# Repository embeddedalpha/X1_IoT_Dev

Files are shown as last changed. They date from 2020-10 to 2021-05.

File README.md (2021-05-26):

# Wi-Fi & LoRA enabled Security Node  

### Check out GrabCAD for STEP Model: https://grabcad.com/library/home-surveillance-node-v1-1
### With generous help from JLCPCB. Check them out on jlcpcb.com

1b83d655-3295-41b9-9d5b-cecb78344af5

Render_1

IOTv1

IOTv1_iso

IOTv1_iso_back

IOTv1_Front

IOTv1_Back

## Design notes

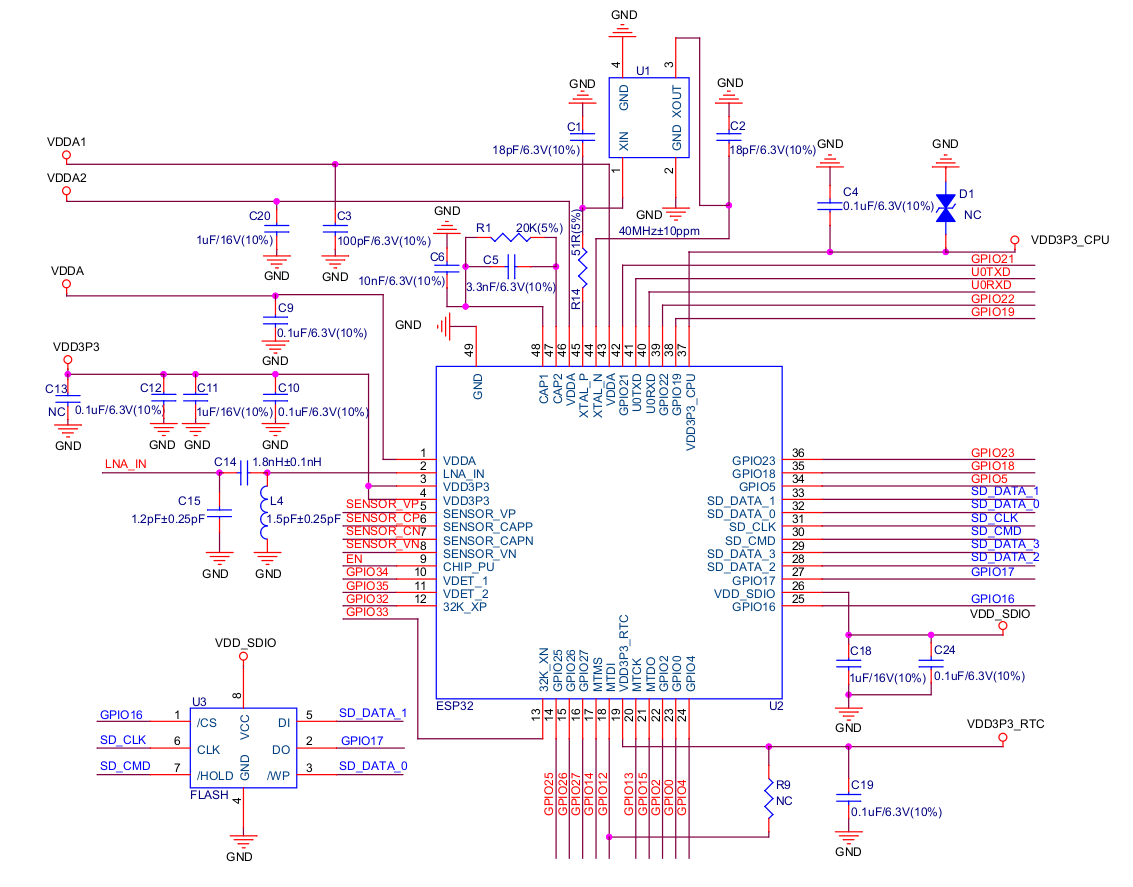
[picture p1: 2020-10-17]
Documents/ESP32-PICO-D4.png

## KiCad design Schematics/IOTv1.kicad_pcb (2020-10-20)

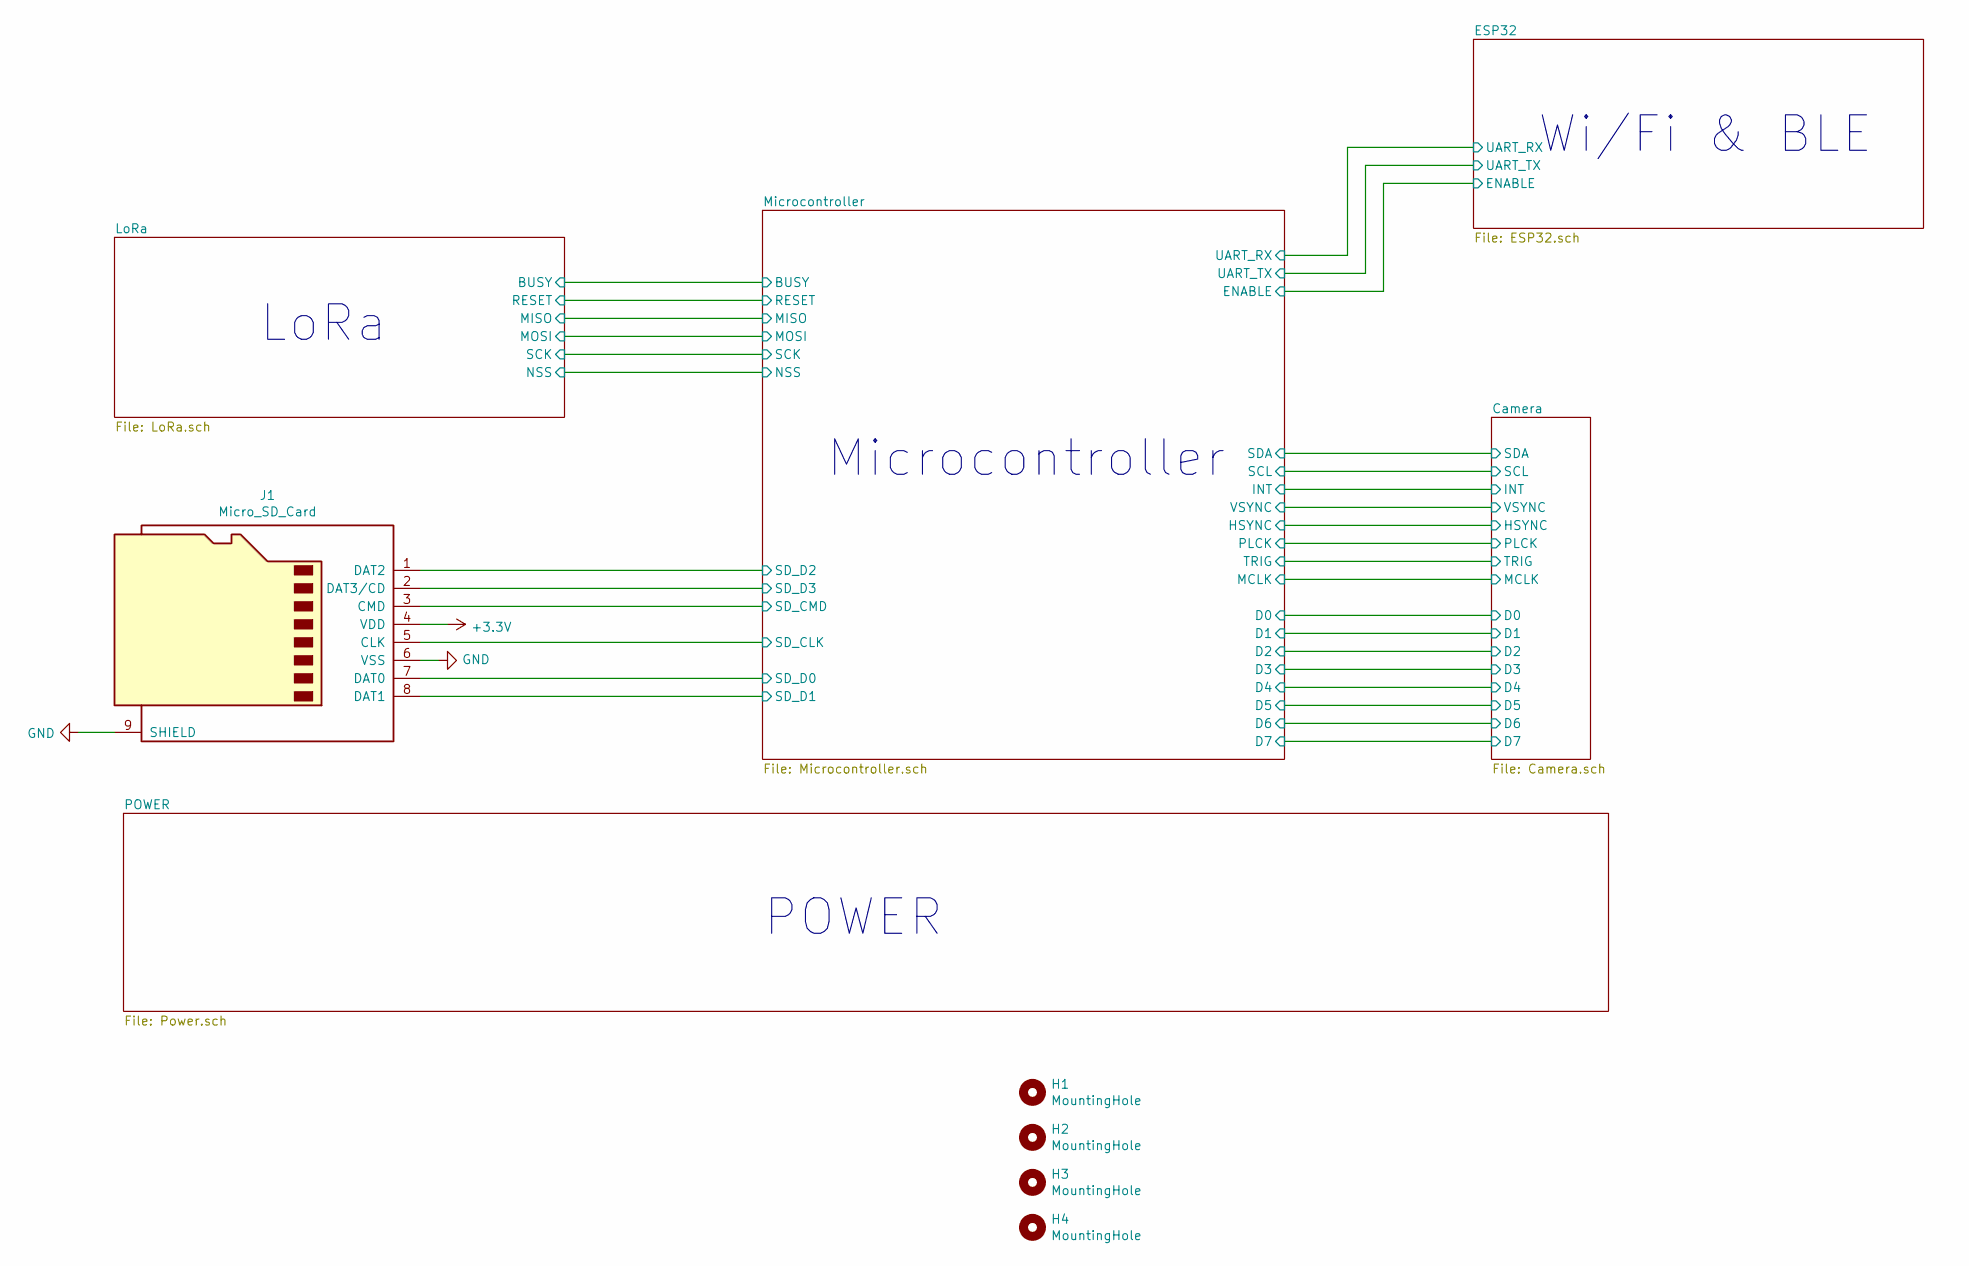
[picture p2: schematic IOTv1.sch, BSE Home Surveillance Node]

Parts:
H1, H2, H3, H4: MountingHole; MountingHole_3.2mm_M3_ISO7380_Pad
J1: Micro_SD_Card; microSD_HC_Wuerth_693072010801

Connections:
+3V3: J1.4 (VDD); also elsewhere on the board
/Microcontroller/SD_CLK: J1.5 (CLK); also elsewhere on the board
/Microcontroller/SD_CMD: J1.3 (CMD); also elsewhere on the board
/Microcontroller/SD_D0: J1.7 (DAT0); also elsewhere on the board
/Microcontroller/SD_D1: J1.8 (DAT1); also elsewhere on the board
/Microcontroller/SD_D2: J1.1 (DAT2); also elsewhere on the board
/Microcontroller/SD_D3: J1.2 (DAT3/CD); also elsewhere on the board
GND: J1.6 (VSS), J1.9 (SHIELD); also elsewhere on the board

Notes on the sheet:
POWER
Microcontroller
LoRa
Wi/Fi & BLE

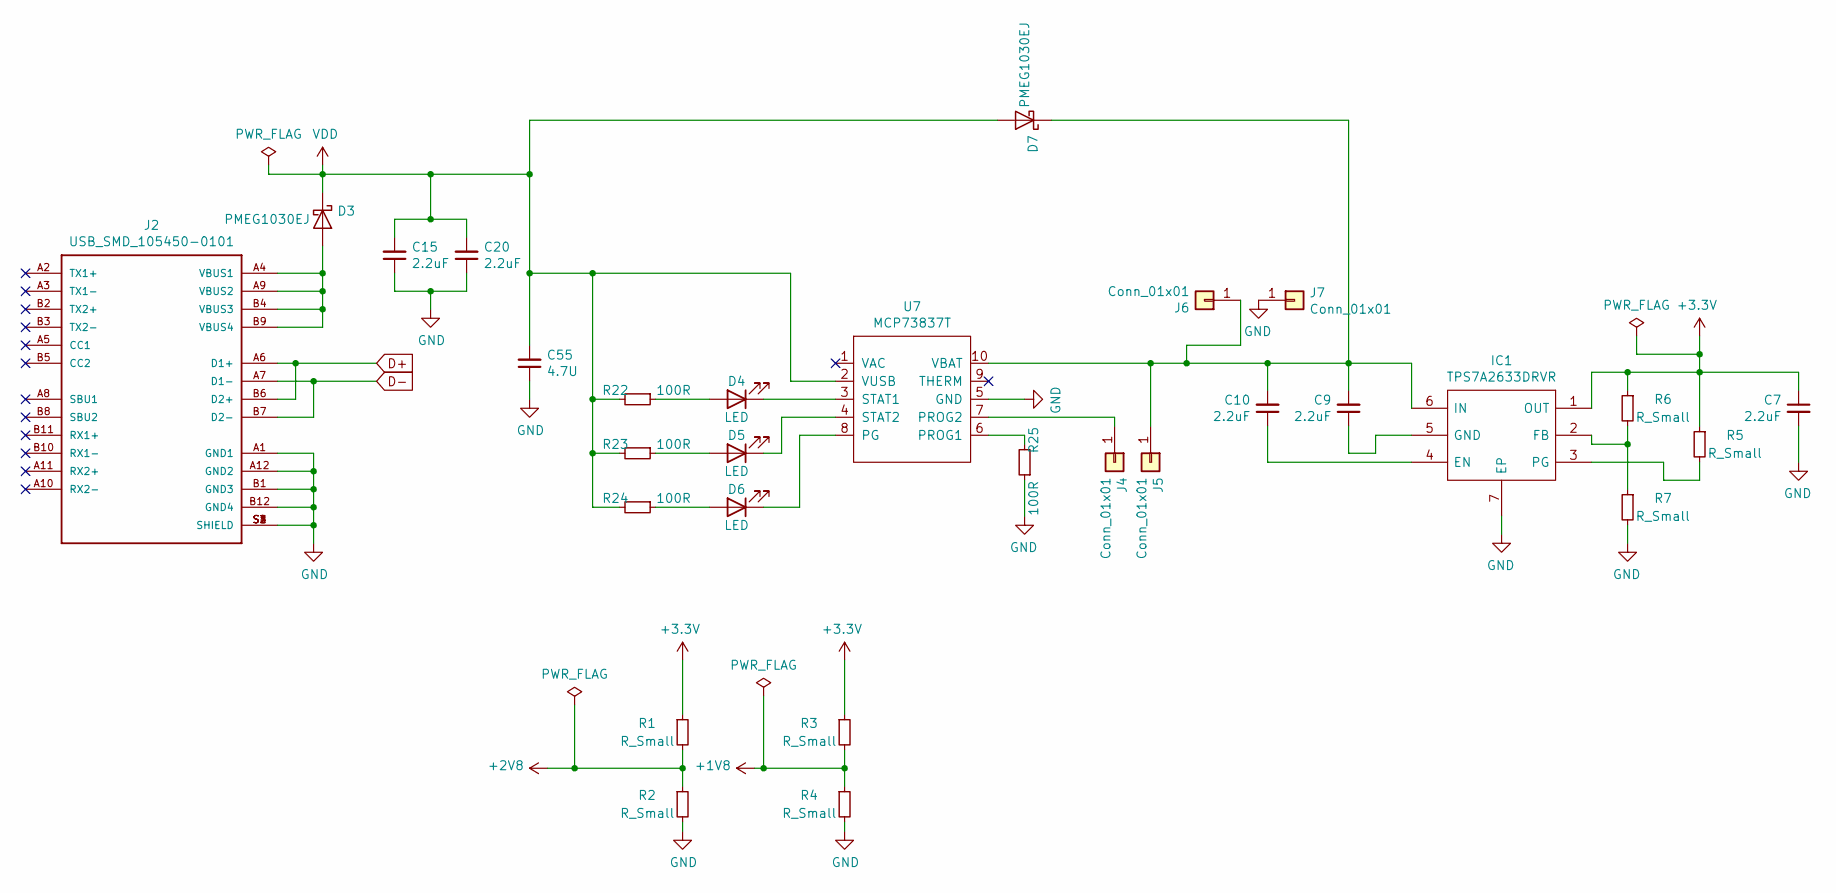
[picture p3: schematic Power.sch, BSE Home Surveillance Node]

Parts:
C7, C9, C10, C15, C20: 2.2uF; C_0402_1005Metric
C55: 4.7U; C_0402_1005Metric
D3, D7: PMEG1030EJ; D_SOD-323F
D4, D5, D6: LED; LED_0402_1005Metric
IC1: TPS7A2633DRVR; Mouser Part Number 595-TPS7A2633DRVR
J2: USB_SMD_105450-0101; MOLEX_105450-0101
J4, J5, J6, J7: Conn_01x01; 2.54MM PIN
R1, R2, R3, R4, R5, R6, R7: R_Small; R_0402_1005Metric
R22, R23, R24, R25: 100R; R_0402_1005Metric
U7: MCP73837T; DFN-10-1EP_3x3mm_P0.5mm_EP1.55x2.48mm

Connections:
+1V8: R3.2, R4.1; also elsewhere on the board
+2V8: R1.2, R2.1; also elsewhere on the board
+3V3: C7.1, IC1.1 (OUT), R1.1, R3.1, R5.1, R6.1; also elsewhere on the board
D+: J2.A6 (D1+), J2.B6 (D2+); also elsewhere on the board
D-: J2.A7 (D1-), J2.B7 (D2-); also elsewhere on the board
GND: C7.2, C15.1, C20.1, C55.1, IC1.7 (EP), J2.A1 (GND1), J2.A12 (GND2), J2.B1 (GND3), J2.B12 (GND4), J2.S1 (SHIELD), J2.S2 (SHIELD), J2.S3 (SHIELD), J2.S4 (SHIELD), J7.1, R2.2, R4.2, R7.2, R25.1, U7.5 (GND); also elsewhere on the board
unnamed: C9.1, IC1.5 (GND)
unnamed: C10.1, IC1.4 (EN)
unnamed: C9.2, C10.2, D7.1 (K), IC1.6 (IN), J5.1, J6.1, U7.10 (VBAT)
unnamed: D3.2 (A), J2.A4 (VBUS1), J2.A9 (VBUS2), J2.B4 (VBUS3), J2.B9 (VBUS4)
unnamed: D4.1 (K), U7.3 (STAT1)
unnamed: D4.2 (A), R22.1
unnamed: D5.1 (K), U7.4 (STAT2)
unnamed: D5.2 (A), R23.1
unnamed: D6.1 (K), U7.8 (PG)
unnamed: D6.2 (A), R24.1
unnamed: IC1.2 (FB), R6.2, R7.1
unnamed: IC1.3 (PG), R5.2
unnamed: J4.1, U7.7 (PROG2)
unnamed: R25.2, U7.6 (PROG1)
VDD: C15.2, C20.2, C55.2, D3.1 (K), D7.2 (A), R22.2, R23.2, R24.2, U7.2 (VUSB); also elsewhere on the board

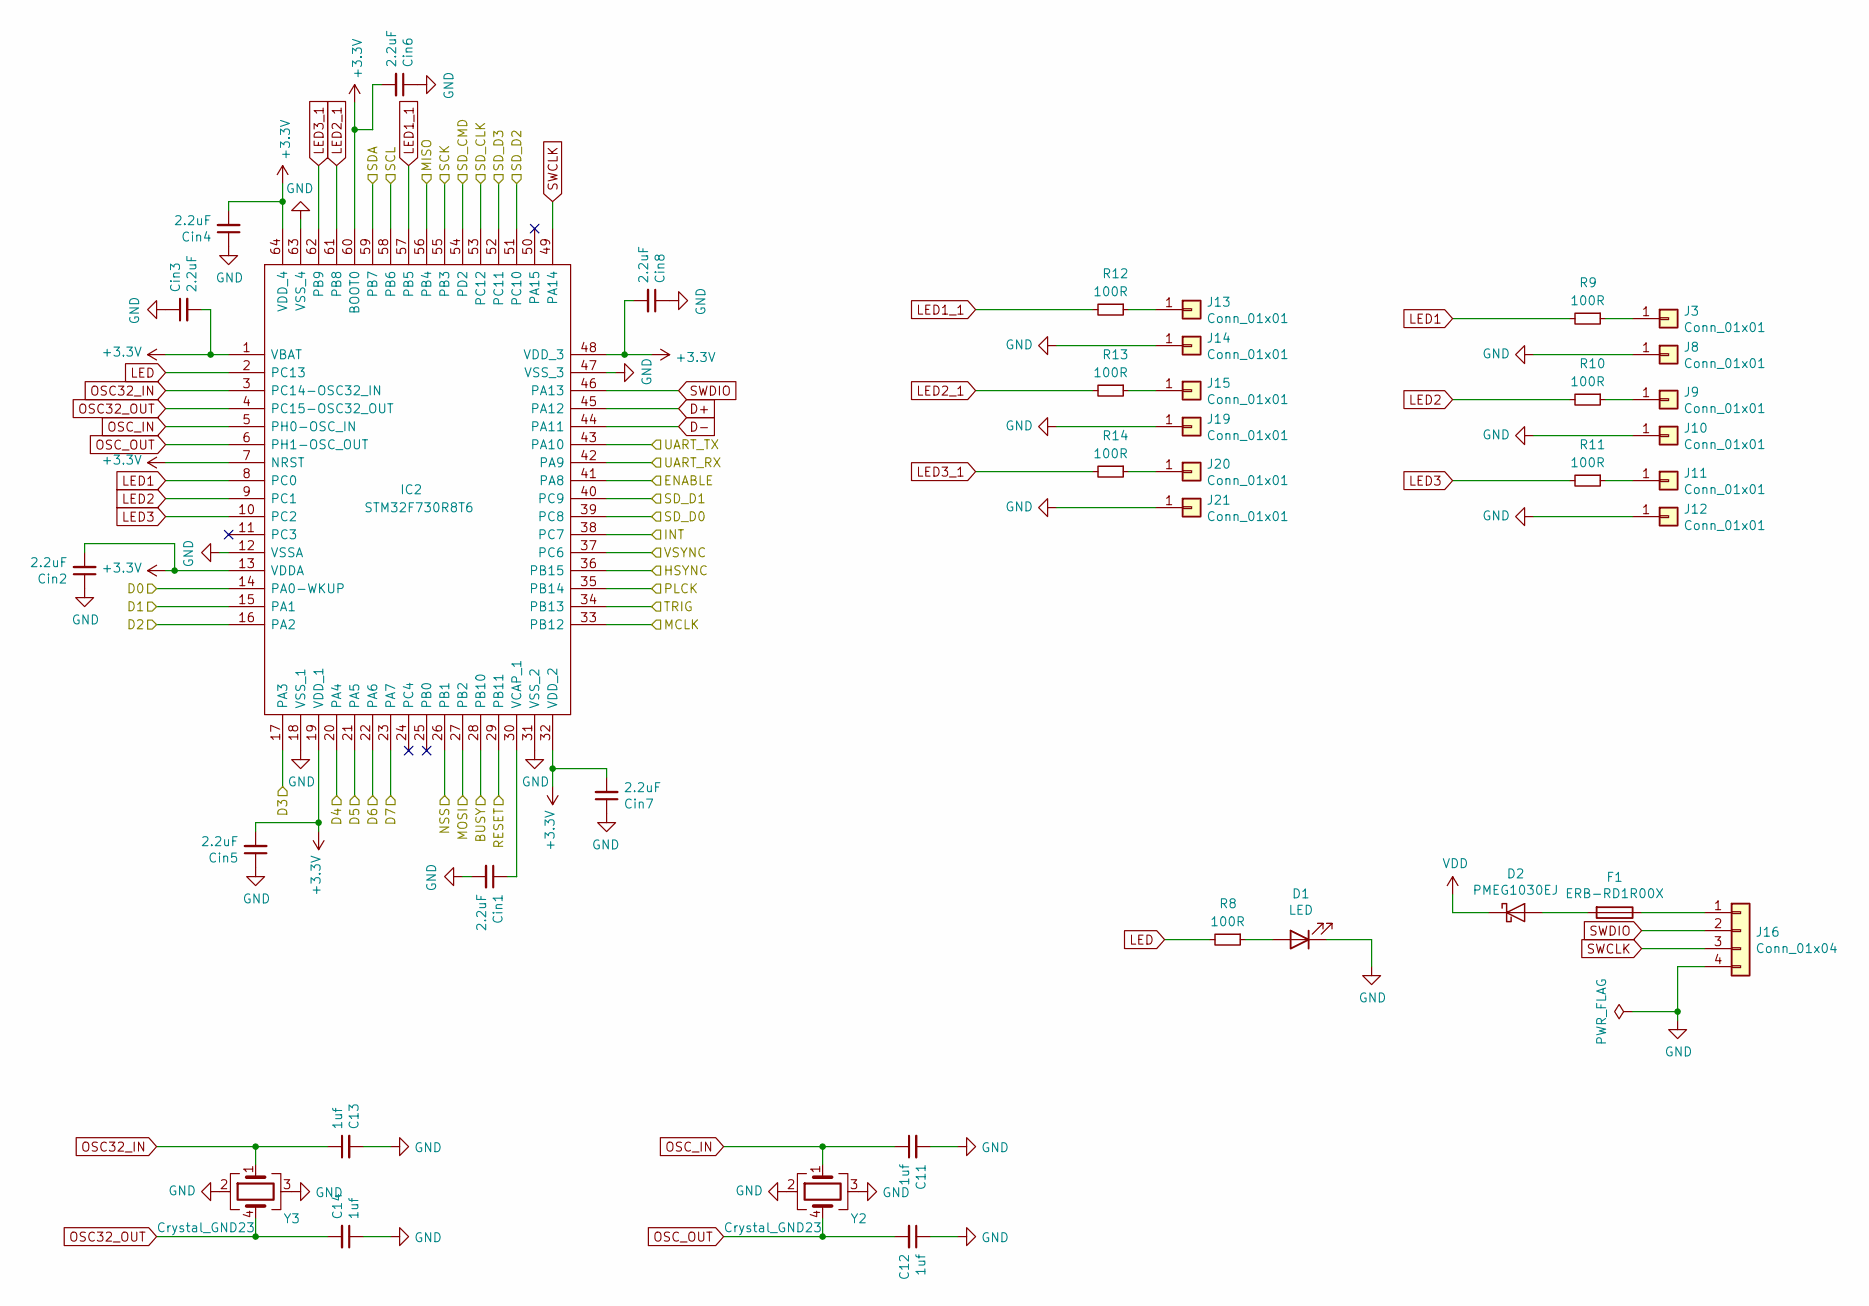
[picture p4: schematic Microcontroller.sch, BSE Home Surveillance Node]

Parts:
C11, C12, C13, C14: 1uf; C_0402_1005Metric
Cin1, Cin2, Cin3, Cin4, Cin5, Cin6, Cin7, Cin8: 2.2uF; C_0402_1005Metric
D1: LED; LED_0402_1005Metric
D2: PMEG1030EJ; D_SOD-323F
F1: ERB-RD1R00X; Fuse_0402_1005Metric
IC2: STM32F730R8T6; QFP50P1200X1200X160-64N; Mouser Part Number 511-STM32F730R8T6
J3, J8, J9, J10, J11, J12, J13, J14, J15, J19, J20, J21: Conn_01x01; 2.54MM PIN
J16: Conn_01x04; SWD_PINS
R8, R9, R10, R11, R12, R13, R14: 100R; R_0402_1005Metric
Y2: Crystal_GND23; Crystal_SMD_SeikoEpson_FA238V-4Pin_3.2x2.5mm
Y3: Crystal_GND23; Crystal_SMD_SeikoEpson_MA406-4Pin_11.7x4.0mm

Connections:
+3V3: Cin2.2, Cin3.2, Cin4.2, Cin5.2, Cin6.2, Cin7.2, Cin8.2, IC2.1 (VBAT), IC2.7 (NRST), IC2.13 (VDDA), IC2.19 (VDD_1), IC2.32 (VDD_2), IC2.48 (VDD_3), IC2.60 (BOOT0), IC2.64 (VDD_4); also elsewhere on the board
/Camera/D0: IC2.14 (PA0-WKUP); also elsewhere on the board
/Camera/D1: IC2.15 (PA1); also elsewhere on the board
/Camera/D2: IC2.16 (PA2); also elsewhere on the board
/Camera/D3: IC2.17 (PA3); also elsewhere on the board
/Camera/D4: IC2.20 (PA4); also elsewhere on the board
/Camera/D5: IC2.21 (PA5); also elsewhere on the board
/Camera/D6: IC2.22 (PA6); also elsewhere on the board
/Camera/D7: IC2.23 (PA7); also elsewhere on the board
/Camera/HSYNC: IC2.36 (PB15); also elsewhere on the board
/Camera/INT: IC2.38 (PC7); also elsewhere on the board
/Camera/MCLK: IC2.33 (PB12); also elsewhere on the board
/Camera/PLCK: IC2.35 (PB14); also elsewhere on the board
/Camera/SCL: IC2.58 (PB6); also elsewhere on the board
/Camera/SDA: IC2.59 (PB7); also elsewhere on the board
/Camera/TRIG: IC2.34 (PB13); also elsewhere on the board
/Camera/VSYNC: IC2.37 (PC6); also elsewhere on the board
/ESP32/ENABLE: IC2.41 (PA8); also elsewhere on the board
/ESP32/UART_RX: IC2.42 (PA9); also elsewhere on the board
/ESP32/UART_TX: IC2.43 (PA10); also elsewhere on the board
/LoRa/BUSY: IC2.28 (PB10); also elsewhere on the board
/LoRa/MISO: IC2.56 (PB4); also elsewhere on the board
/LoRa/MOSI: IC2.27 (PB2); also elsewhere on the board
/LoRa/NSS: IC2.26 (PB1); also elsewhere on the board
/LoRa/RESET: IC2.29 (PB11); also elsewhere on the board
/LoRa/SCK: IC2.55 (PB3); also elsewhere on the board
/Microcontroller/SD_CLK: IC2.53 (PC12); also elsewhere on the board
/Microcontroller/SD_CMD: IC2.54 (PD2); also elsewhere on the board
/Microcontroller/SD_D0: IC2.39 (PC8); also elsewhere on the board
/Microcontroller/SD_D1: IC2.40 (PC9); also elsewhere on the board
/Microcontroller/SD_D2: IC2.51 (PC10); also elsewhere on the board
/Microcontroller/SD_D3: IC2.52 (PC11); also elsewhere on the board
D+: IC2.45 (PA12); also elsewhere on the board
D-: IC2.44 (PA11); also elsewhere on the board
GND: C11.2, C12.1, C13.2, C14.1, Cin1.2, Cin2.1, Cin3.1, Cin4.1, Cin5.1, Cin6.1, Cin7.1, Cin8.1, D1.1 (K), IC2.12 (VSSA), IC2.18 (VSS_1), IC2.31 (VSS_2), IC2.47 (VSS_3), IC2.63 (VSS_4), J8.1, J10.1, J12.1, J14.1, J16.4, J19.1, J21.1, Y2.2, Y2.3, Y3.2, Y3.3; also elsewhere on the board
LED: IC2.2 (PC13), R8.2
LED1: IC2.8 (PC0), R9.2
LED1_1: IC2.57 (PB5), R12.2
LED2: IC2.9 (PC1), R10.2
LED2_1: IC2.61 (PB8), R13.2
LED3: IC2.10 (PC2), R11.2
LED3_1: IC2.62 (PB9), R14.2
unnamed: Cin1.1, IC2.30 (VCAP_1)
unnamed: D1.2 (A), R8.1
unnamed: D2.2 (A), F1.2
unnamed: F1.1, J16.1
unnamed: J3.1, R9.1
unnamed: J9.1, R10.1
unnamed: J11.1, R11.1
unnamed: J13.1, R12.1
unnamed: J15.1, R13.1
unnamed: J20.1, R14.1
OSC32_IN: C13.1, IC2.3 (PC14-OSC32_IN), Y3.1
OSC32_OUT: C14.2, IC2.4 (PC15-OSC32_OUT), Y3.4
OSC_IN: C11.1, IC2.5 (PH0-OSC_IN), Y2.1
OSC_OUT: C12.2, IC2.6 (PH1-OSC_OUT), Y2.4
SWCLK: IC2.49 (PA14), J16.3
SWDIO: IC2.46 (PA13), J16.2
VDD: D2.1 (K); also elsewhere on the board

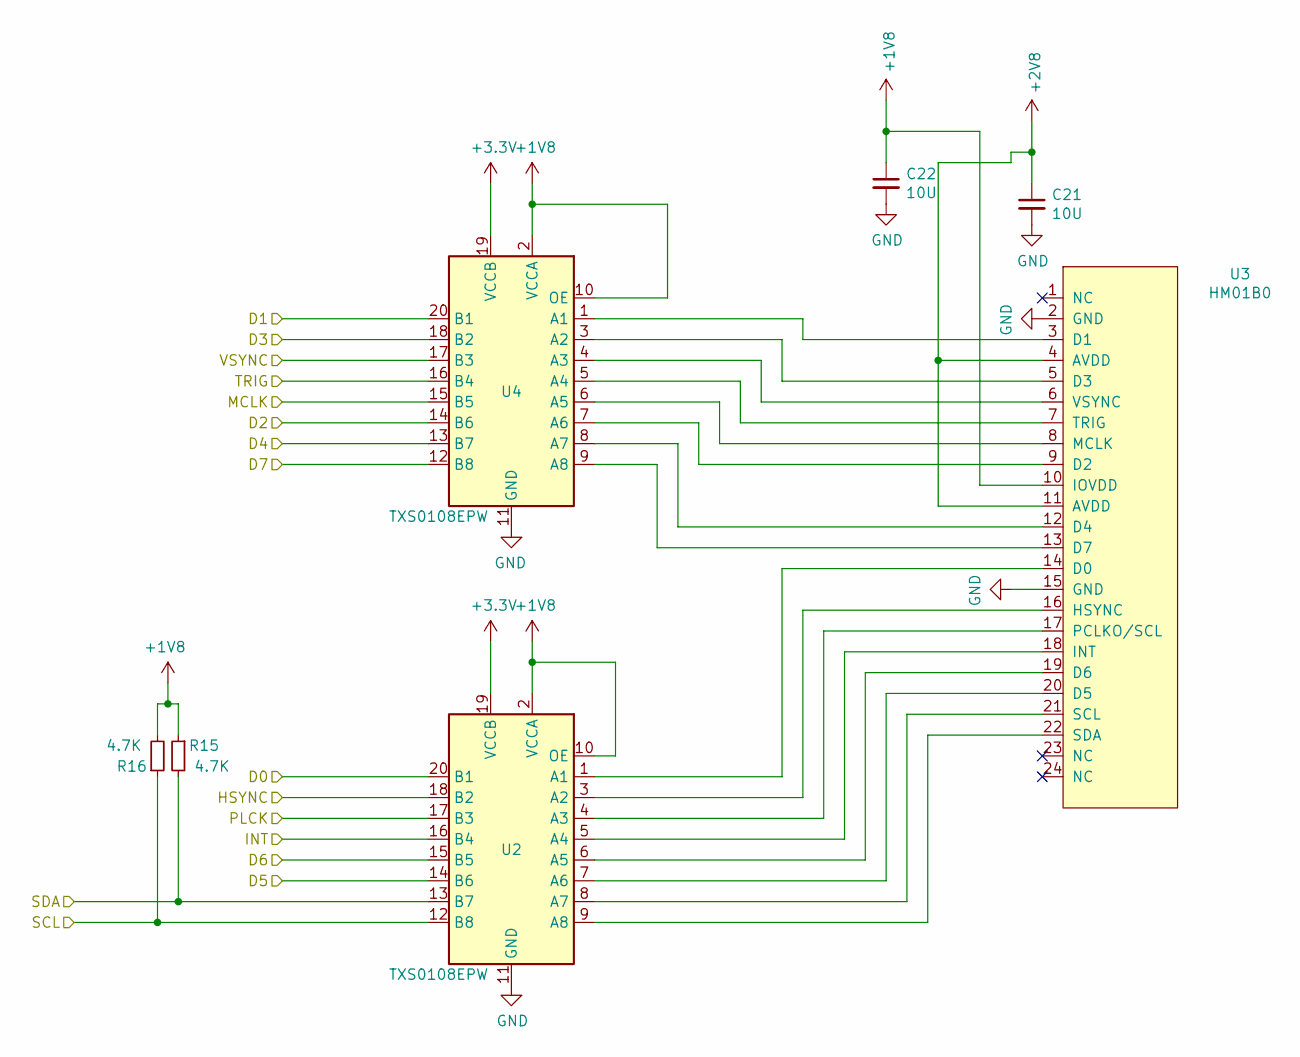
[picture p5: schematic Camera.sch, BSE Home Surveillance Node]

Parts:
C21, C22: 10U; C_0402_1005Metric
R15, R16: 4.7K; R_0402_1005Metric
U2, U4: TXS0108EPW; TSSOP-20_4.4x6.5mm_P0.65mm
U3: HM01B0

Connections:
+1V8: C22.1, R15.1, R16.2, U2.2 (VCCA), U2.10 (OE), U3.10 (IOVDD), U4.2 (VCCA), U4.10 (OE); also elsewhere on the board
+2V8: C21.1, U3.4 (AVDD), U3.11 (AVDD); also elsewhere on the board
+3V3: U2.19 (VCCB), U4.19 (VCCB); also elsewhere on the board
/Camera/D0: U2.20 (B1); also elsewhere on the board
/Camera/D1: U4.20 (B1); also elsewhere on the board
/Camera/D2: U4.14 (B6); also elsewhere on the board
/Camera/D3: U4.18 (B2); also elsewhere on the board
/Camera/D4: U4.13 (B7); also elsewhere on the board
/Camera/D5: U2.14 (B6); also elsewhere on the board
/Camera/D6: U2.15 (B5); also elsewhere on the board
/Camera/D7: U4.12 (B8); also elsewhere on the board
/Camera/HSYNC: U2.18 (B2); also elsewhere on the board
/Camera/INT: U2.16 (B4); also elsewhere on the board
/Camera/MCLK: U4.15 (B5); also elsewhere on the board
/Camera/PLCK: U2.17 (B3); also elsewhere on the board
/Camera/SCL: R16.1, U2.12 (B8); also elsewhere on the board
/Camera/SDA: R15.2, U2.13 (B7); also elsewhere on the board
/Camera/TRIG: U4.16 (B4); also elsewhere on the board
/Camera/VSYNC: U4.17 (B3); also elsewhere on the board
GND: C21.2, C22.2, U2.11 (GND), U3.2 (GND), U3.15 (GND), U4.11 (GND); also elsewhere on the board
unnamed: U2.1 (A1), U3.14 (D0)
unnamed: U2.3 (A2), U3.16 (HSYNC)
unnamed: U2.4 (A3), U3.17 (PCLKO/SCL)
unnamed: U2.5 (A4), U3.18 (INT)
unnamed: U2.6 (A5), U3.19 (D6)
unnamed: U2.7 (A6), U3.20 (D5)
unnamed: U2.8 (A7), U3.21 (SCL)
unnamed: U2.9 (A8), U3.22 (SDA)
unnamed: U3.3 (D1), U4.1 (A1)
unnamed: U3.5 (D3), U4.3 (A2)
unnamed: U3.6 (VSYNC), U4.4 (A3)
unnamed: U3.7 (TRIG), U4.5 (A4)
unnamed: U3.8 (MCLK), U4.6 (A5)
unnamed: U3.9 (D2), U4.7 (A6)
unnamed: U3.12 (D4), U4.8 (A7)
unnamed: U3.13 (D7), U4.9 (A8)

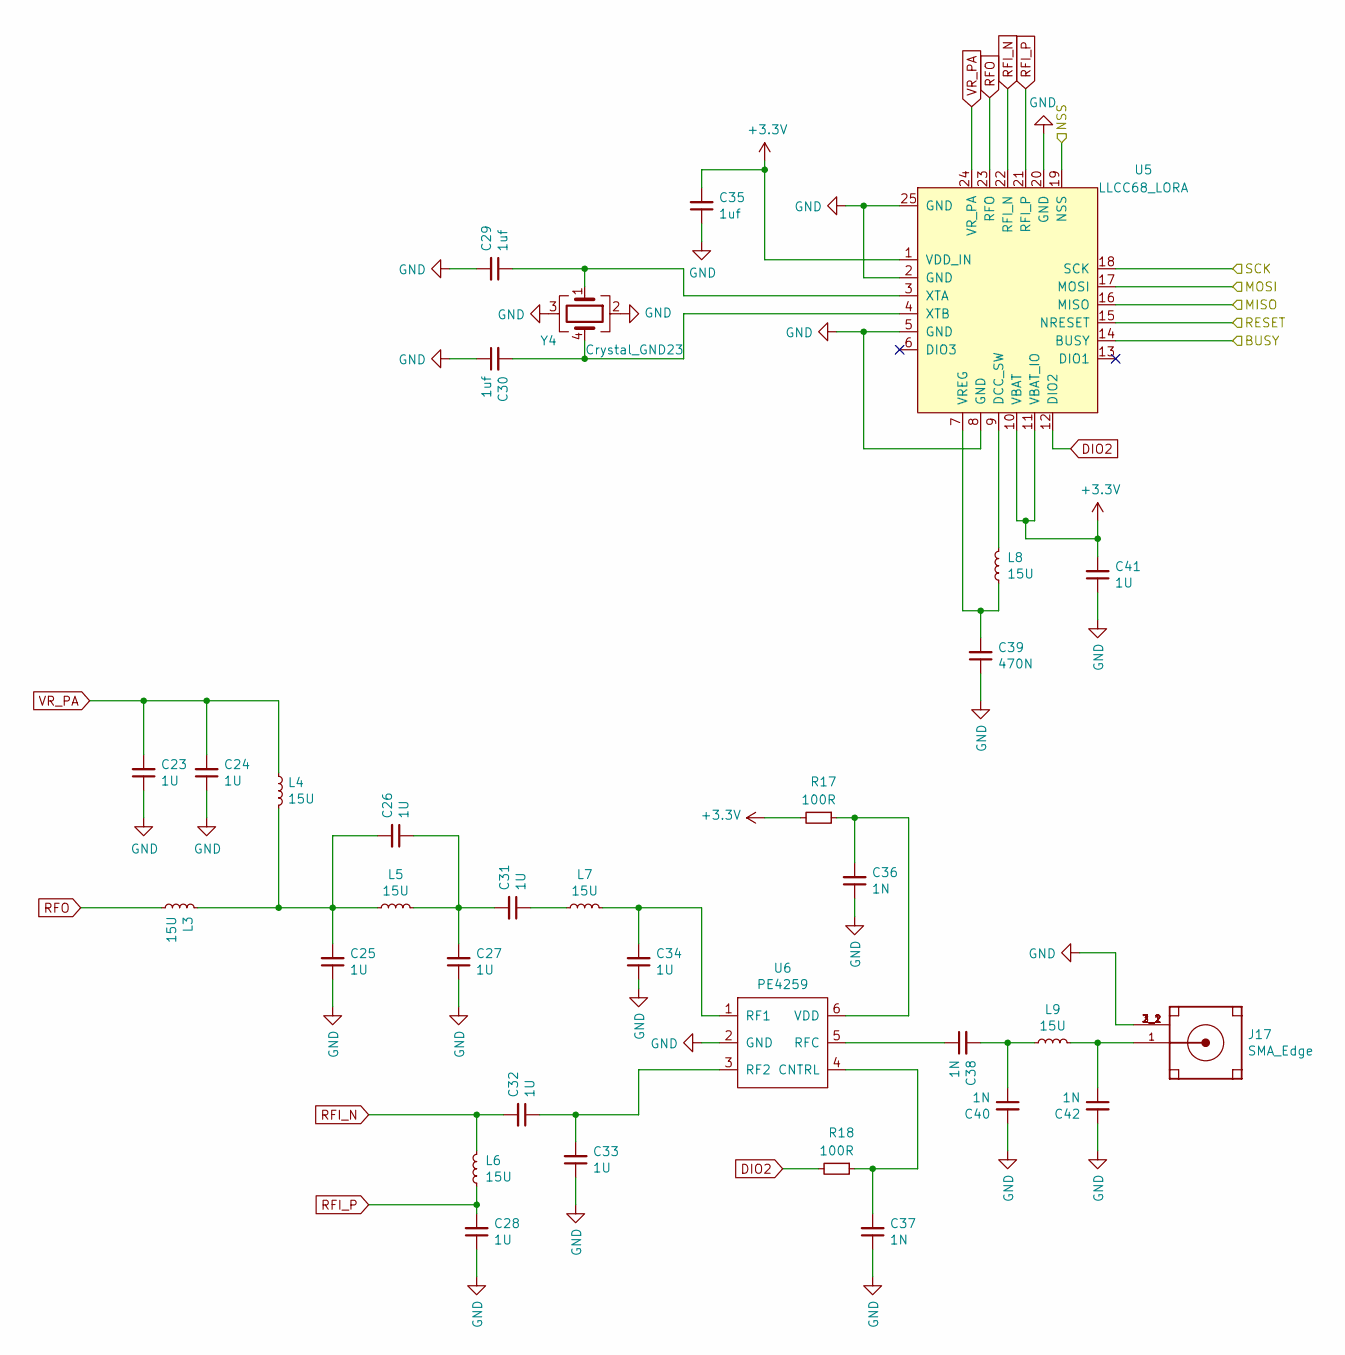
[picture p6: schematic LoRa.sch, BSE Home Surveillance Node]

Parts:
C23, C24, C25, C26, C27, C28, C31, C32, C33, C34, C41: 1U; C_0402_1005Metric
C29, C30, C35: 1uf; C_0402_1005Metric
C36, C37, C38, C40, C42: 1N; C_0402_1005Metric
C39: 470N; C_0402_1005Metric
J17: SMA_Edge; SMA-J-P-H-ST-EM1
L3, L4, L5, L6, L7, L8, L9: 15U; L_0402_1005Metric
R17, R18: 100R; R_0402_1005Metric
U5: LLCC68_LORA; QFN-24-1EP_4x4mm_P0.5mm_EP2.6x2.6mm
U6: PE4259; SOT65P215X110-6N
Y4: Crystal_GND23; Crystal_SMD_SeikoEpson_FA238V-4Pin_3.2x2.5mm

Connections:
+3V3: C35.2, C41.2, R17.2, U5.1 (VDD_IN), U5.10 (VBAT), U5.11 (VBAT_IO); also elsewhere on the board
/LoRa/BUSY: U5.14 (BUSY); also elsewhere on the board
/LoRa/MISO: U5.16 (MISO); also elsewhere on the board
/LoRa/MOSI: U5.17 (MOSI); also elsewhere on the board
/LoRa/NSS: U5.19 (NSS); also elsewhere on the board
/LoRa/RESET: U5.15 (NRESET); also elsewhere on the board
/LoRa/SCK: U5.18 (SCK); also elsewhere on the board
DIO2: R18.2, U5.12 (DIO2)
GND: C23.1, C24.1, C25.1, C27.1, C28.1, C29.2, C30.1, C33.1, C34.1, C35.1, C36.1, C37.1, C39.1, C40.2, C41.1, C42.2, J17.2_1 (GND), J17.2_2 (GND), J17.3_1 (GND), J17.3_2 (GND), U5.2 (GND), U5.5 (GND), U5.8 (GND), U5.20 (GND), U5.25 (GND), U6.2 (GND), Y4.2, Y4.3; also elsewhere on the board
unnamed: C25.2, C26.2, L3.2, L4.2, L5.1
unnamed: C26.1, C27.2, C31.2, L5.2
unnamed: C29.1, U5.3 (XTA), Y4.1
unnamed: C30.2, U5.4 (XTB), Y4.4
unnamed: C31.1, L7.1
unnamed: C32.1, C33.2, U6.3 (RF2)
unnamed: C34.2, L7.2, U6.1 (RF1)
unnamed: C36.2, R17.1, U6.6 (VDD)
unnamed: C37.2, R18.1, U6.4 (CNTRL)
unnamed: C38.1, U6.5 (RFC)
unnamed: C38.2, C40.1, L9.1
unnamed: C39.2, L8.1, U5.7 (VREG)
unnamed: C42.1, J17.1 (SIGNAL), L9.2
unnamed: L8.2, U5.9 (DCC_SW)
RFI_N: C32.2, L6.2, U5.22 (RFI_N)
RFI_P: C28.2, L6.1, U5.21 (RFI_P)
RFO: L3.1, U5.23 (RFO)
VR_PA: C23.2, C24.2, L4.1, U5.24 (VR_PA)

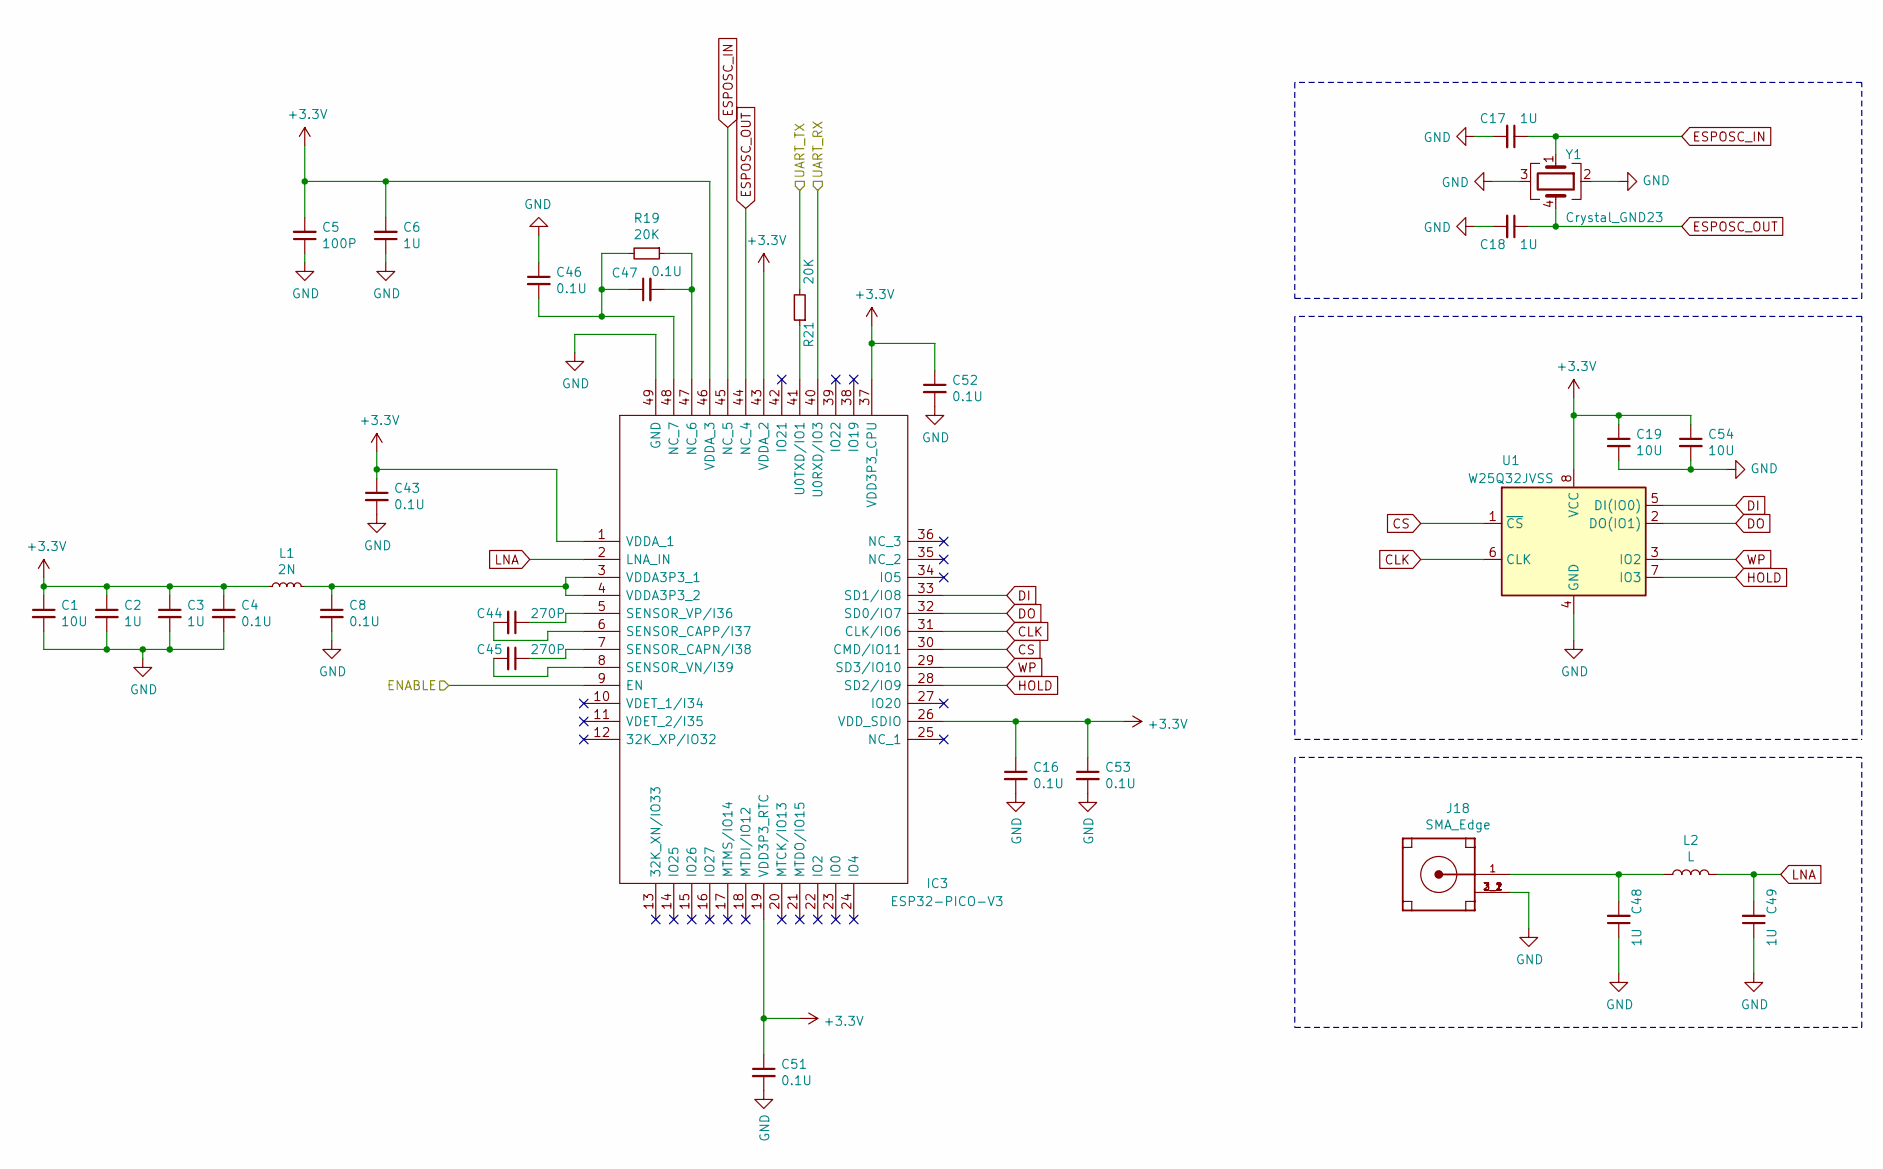
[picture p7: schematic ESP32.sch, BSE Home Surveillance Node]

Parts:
C1, C19, C54: 10U; C_0402_1005Metric
C2, C3, C6, C17, C18, C48, C49: 1U; C_0402_1005Metric
C4, C8, C16, C43, C46, C47, C51, C52, C53: 0.1U; C_0402_1005Metric
C5: 100P; C_0402_1005Metric
C44, C45: 270P; C_0402_1005Metric
IC3: ESP32-PICO-V3; ESP32PICOV3; Mouser Part Number 356-ESP32-PICO-V3
J18: SMA_Edge; SMA-J-P-H-ST-EM1
L1: 2N; L_0402_1005Metric
L2: L; L_0402_1005Metric
R19, R21: 20K; R_0402_1005Metric
U1: W25Q32JVSS; SOIC-8_5.23x5.23mm_P1.27mm
Y1: Crystal_GND23; Crystal_SMD_TXC_7M-4Pin_3.2x2.5mm

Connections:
+3V3: C1.1, C2.1, C3.1, C4.1, C5.2, C6.2, C16.1, C19.1, C43.1, C51.1, C52.1, C53.1, C54.1, IC3.1 (VDDA_1), IC3.19 (VDD3P3_RTC), IC3.26 (VDD_SDIO), IC3.37 (VDD3P3_CPU), IC3.43 (VDDA_2), IC3.46 (VDDA_3), L1.1, U1.8 (VCC); also elsewhere on the board
/ESP32/ENABLE: IC3.9 (EN); also elsewhere on the board
/ESP32/UART_RX: IC3.40 (U0RXD/IO3); also elsewhere on the board
/ESP32/UART_TX: R21.2; also elsewhere on the board
CLK: IC3.31 (CLK/IO6), U1.6 (CLK)
CS: IC3.30 (CMD/IO11), U1.1 (~CS)
DI: IC3.33 (SD1/IO8), U1.5 (DI(IO0))
DO: IC3.32 (SD0/IO7), U1.2 (DO(IO1))
ESPOSC_IN: C17.1, IC3.45 (NC_5), Y1.1
ESPOSC_OUT: C18.1, IC3.44 (NC_4), Y1.4
GND: C1.2, C2.2, C3.2, C4.2, C5.1, C6.1, C8.2, C16.2, C17.2, C18.2, C19.2, C43.2, C46.1, C48.1, C49.1, C51.2, C52.2, C53.2, C54.2, IC3.49 (GND), J18.2_1 (GND), J18.2_2 (GND), J18.3_1 (GND), J18.3_2 (GND), U1.4 (GND), Y1.2, Y1.3; also elsewhere on the board
HOLD: IC3.28 (SD2/IO9), U1.7 (IO3)
LNA: C49.2, IC3.2 (LNA_IN), L2.2
unnamed: C8.1, IC3.3 (VDDA3P3_1), IC3.4 (VDDA3P3_2), L1.2
unnamed: C44.1, IC3.5 (SENSOR_VP/I36)
unnamed: C44.2, IC3.6 (SENSOR_CAPP/I37)
unnamed: C45.1, IC3.7 (SENSOR_CAPN/I38)
unnamed: C45.2, IC3.8 (SENSOR_VN/I39)
unnamed: C46.2, C47.1, IC3.48 (NC_7), R19.2
unnamed: C47.2, IC3.47 (NC_6), R19.1
unnamed: C48.2, J18.1 (SIGNAL), L2.1
unnamed: IC3.41 (U0TXD/IO1), R21.1
WP: IC3.29 (SD3/IO10), U1.3 (IO2)

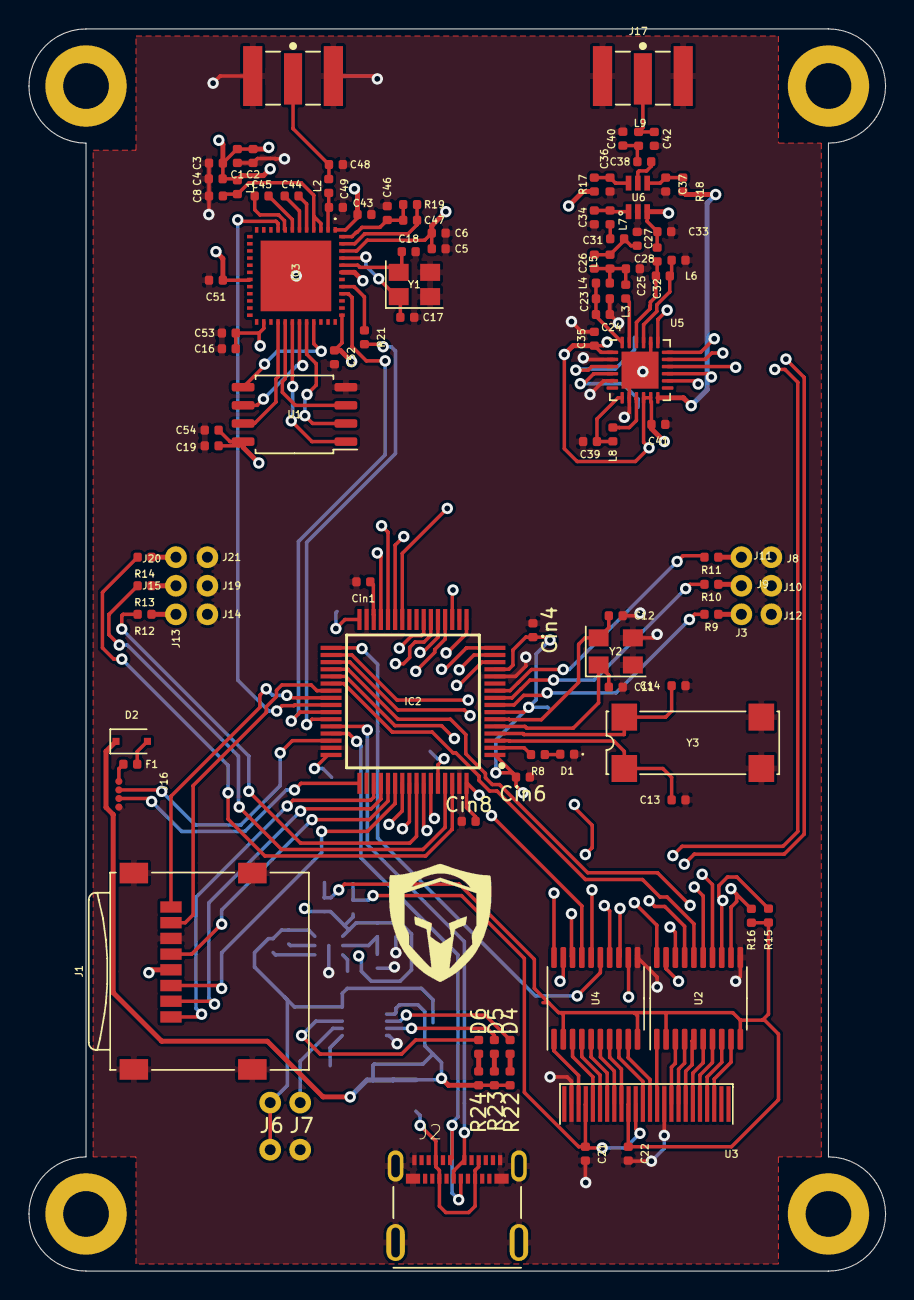
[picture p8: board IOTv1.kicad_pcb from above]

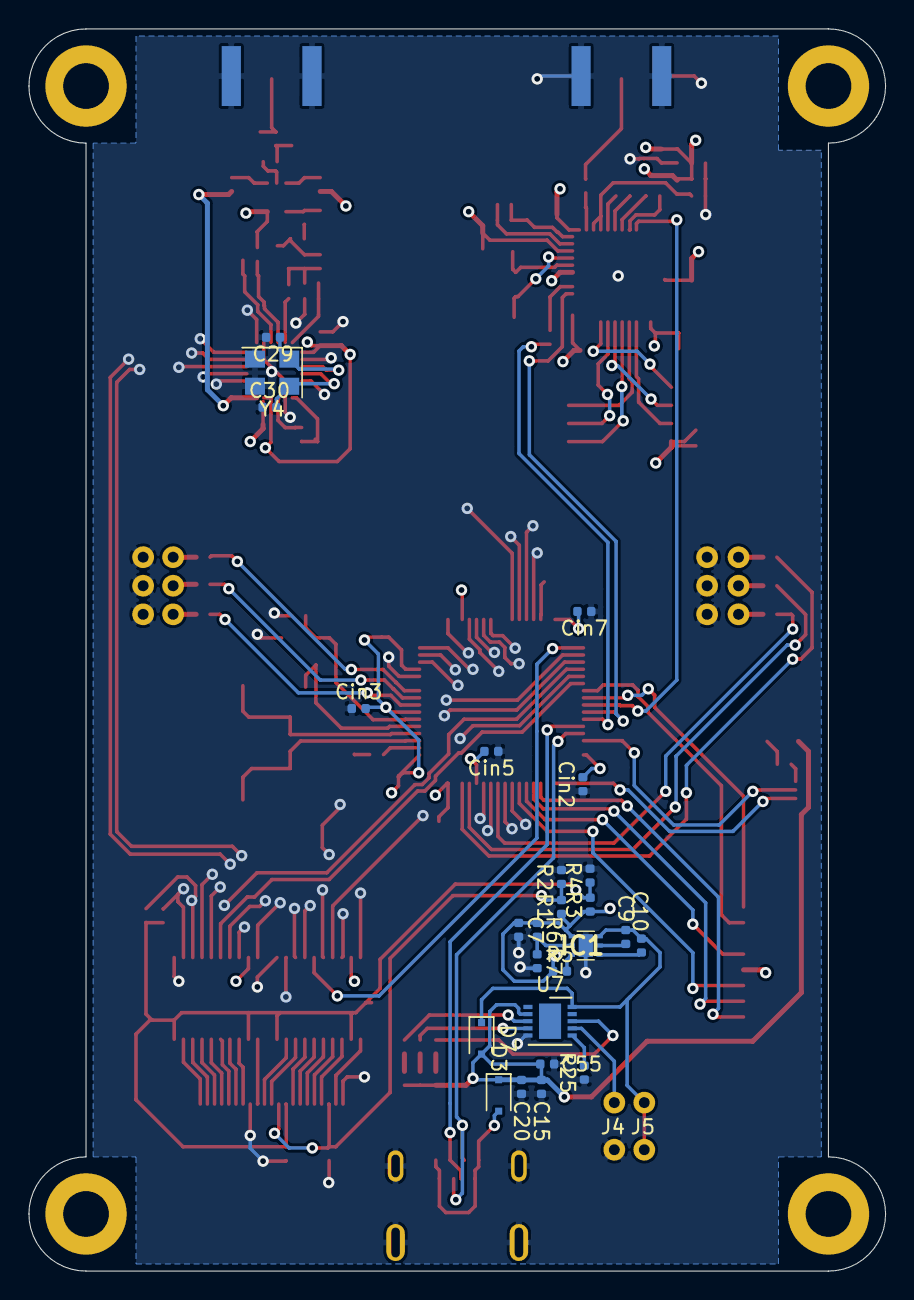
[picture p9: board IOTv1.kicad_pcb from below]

Board: 4 copper layers, 60.0 x 87.0 mm, 142 parts (27 on the bottom side), 128 nets.
